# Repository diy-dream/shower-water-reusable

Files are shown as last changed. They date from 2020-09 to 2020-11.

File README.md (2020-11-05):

# Shower water reusable

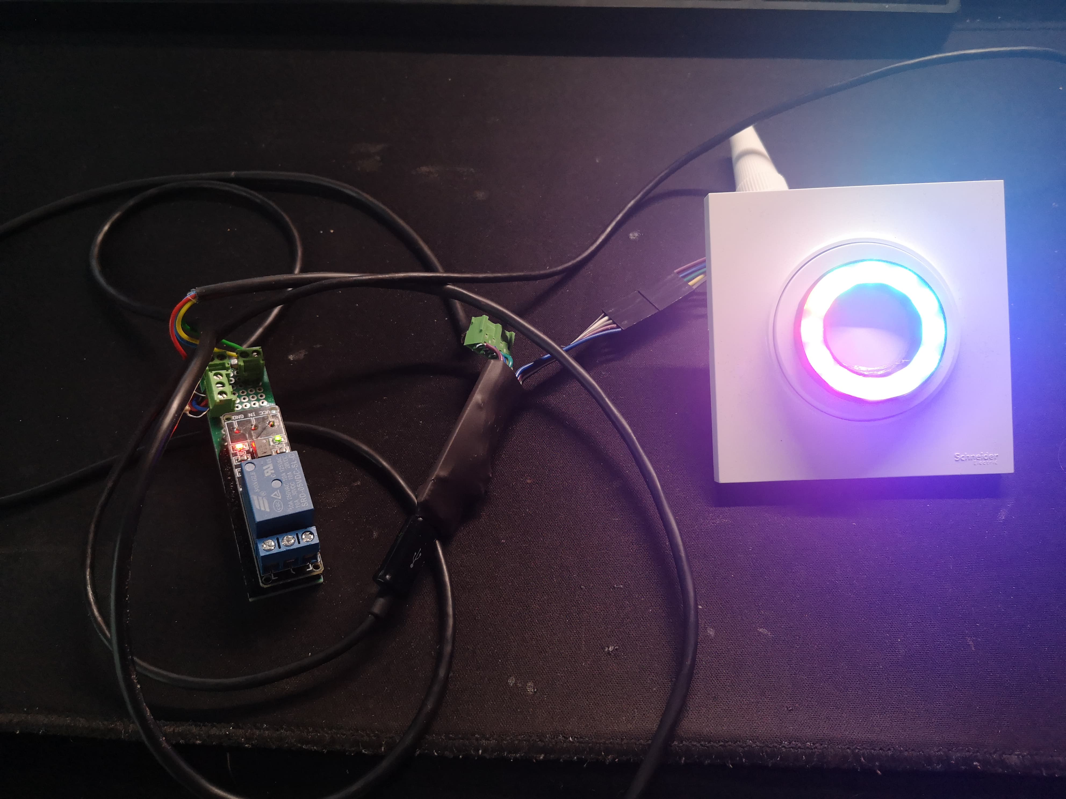
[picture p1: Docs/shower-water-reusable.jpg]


## Table of contents
* [Summary](#summary)
* [Requirements](#requirements)
* [Hardware](#hardware)
* [LICENCE](#licence)

## Summary

The idea of this project is to set up a system for reused the the cold water from the shower. This project is intended for my parents who have tanks to collect rainwater which allows them to supply the toilets with water and also to water the plants in summer.

When we take a shower we wait for the water to get hot, so we are wasting water that could very well be used for something else. So I created a system that allows cold water to be sent to the tubs and to detect / notify when the shower water is ready for the user.

## Requirements

* STM32CubeIDE 1.4.0

## Hardware

* STM32L412kb
* LED Ring 5V RGB WS2812B 12-Bit 37mm
* DS18B20
* Module relay 5V

## LICENCE	

TODO

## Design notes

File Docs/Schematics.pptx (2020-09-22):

## DAD PROJECT

Shower water reusable

## Schematics

Power Supply

5V

RGB RING

5V

D2

Temperature sensor

5V

VCC

D6

GND

GND

5V

GND

Arduino

D1

10 kOhms

GND

Switch

Solenoid valve

Relay

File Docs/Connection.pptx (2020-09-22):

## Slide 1

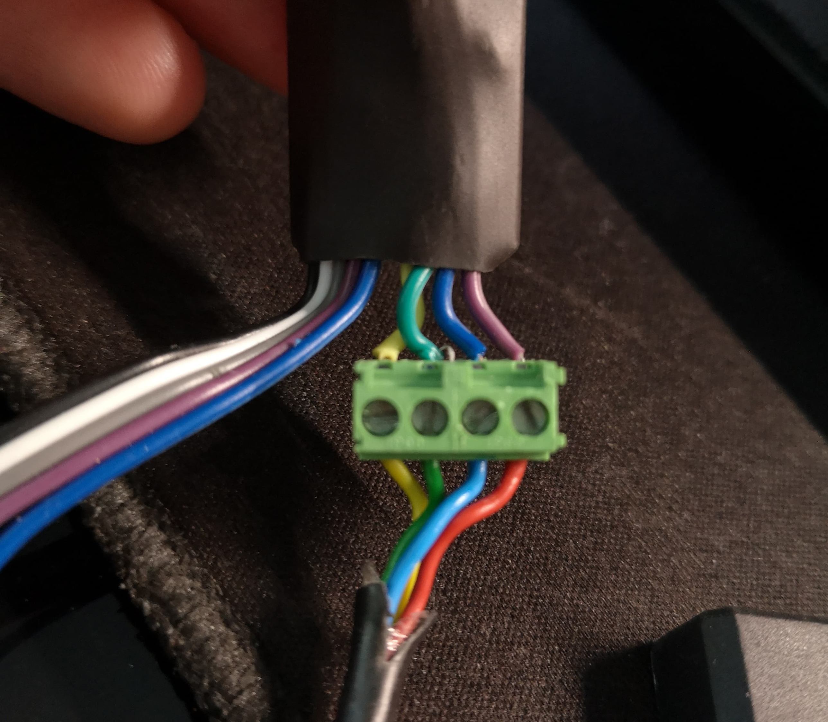
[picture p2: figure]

RELAY | TEMP | VCC | GND

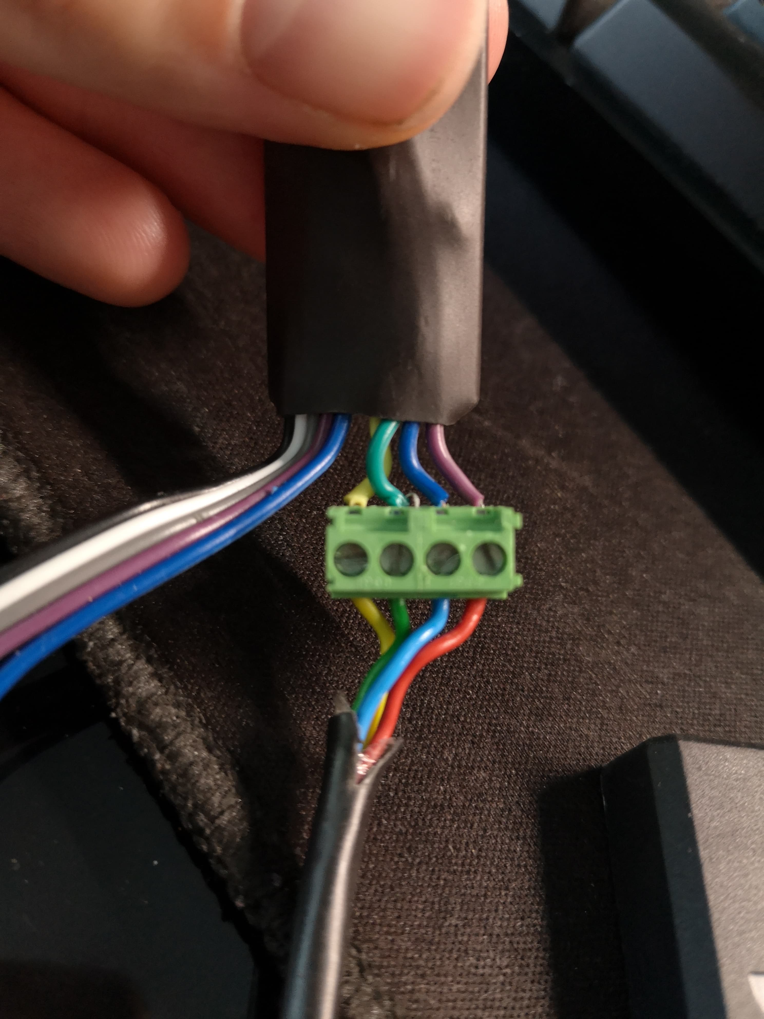
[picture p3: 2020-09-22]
Docs/connection.jpg

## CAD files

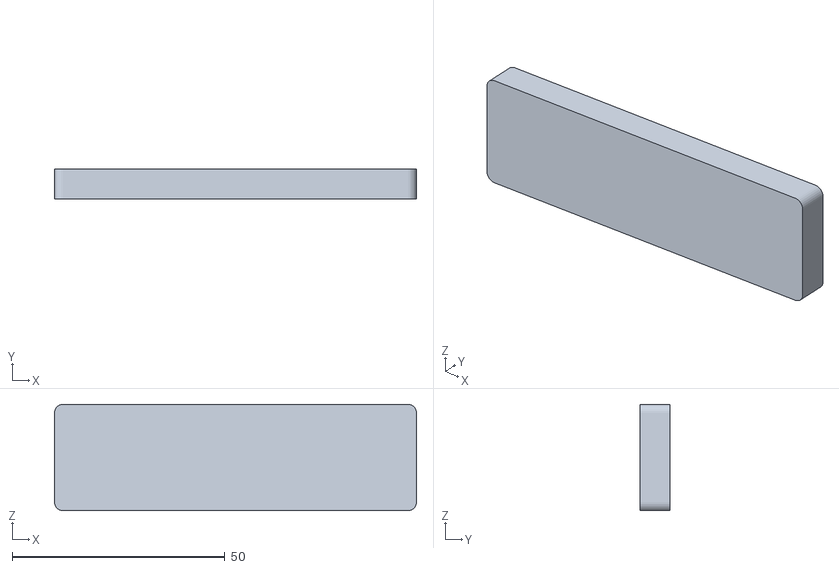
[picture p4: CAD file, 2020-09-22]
3d-model/RELAY_CASE_PART_1 v2.stl
85.0 x 7.00 x 25.0

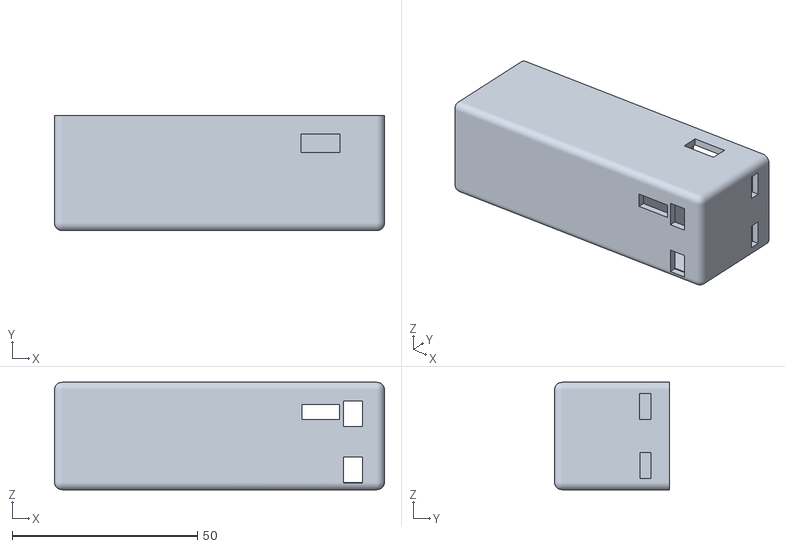
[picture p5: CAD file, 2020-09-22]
3d-model/RELAY_CASE_PART_2 v2.stl
89.0 x 31.0 x 29.0

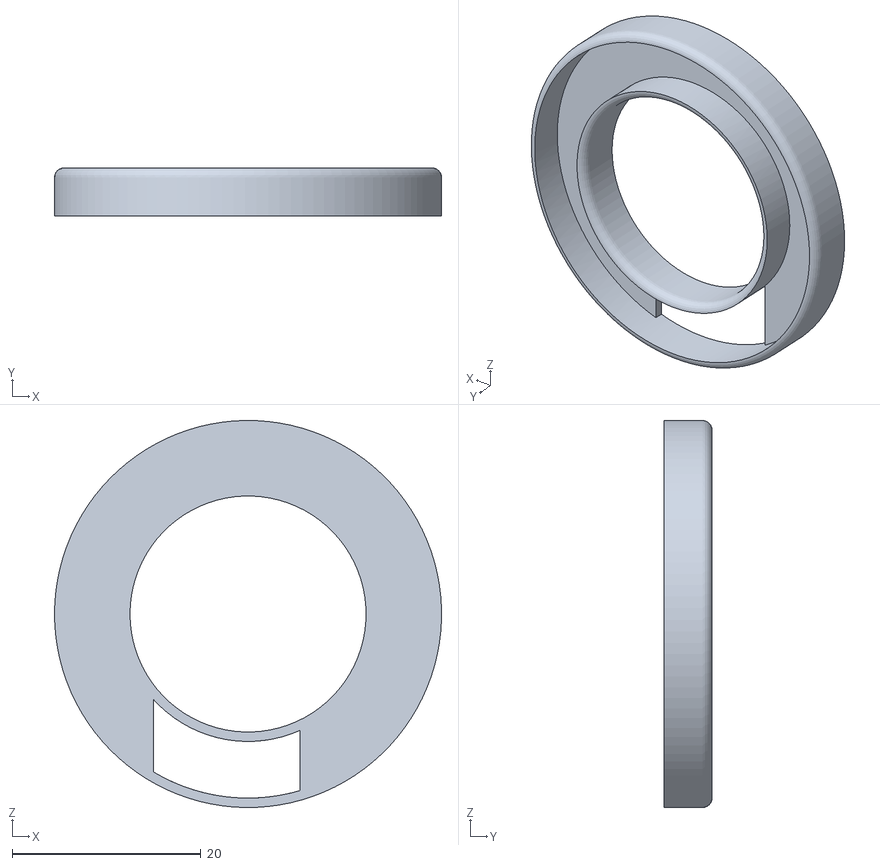
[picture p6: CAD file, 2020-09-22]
3d-model/RING_RGB_LED_SUPPORT v4.stl
41.0 x 5.10 x 41.0

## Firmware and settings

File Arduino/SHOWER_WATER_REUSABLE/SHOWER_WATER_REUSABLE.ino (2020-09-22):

#include "LowPower.h"
#include <OneWire.h>
#include <DallasTemperature.h>
#include <Adafruit_NeoPixel.h>
#include <SimpleCLI.h>

#define DEFAULT_TEMP_MIN 20 
#define DEFAULT_TEMP_MAX 28

#define TIMEOUT_FINISH 10
#define TIMEOUT_ERROR 10

#define RING_LEDS_PIN 6

// Data wire is plugged into port 3 on the Arduino
#define ONE_WIRE_BUS 3

#define SOLENOID_VALVE_PIN 4

#define SWITCH_PIN 2

// Parameter 1 = number of pixels in strip
// Parameter 2 = Arduino pin number (most are valid)
// Parameter 3 = pixel type flags, add together as needed:
//   NEO_KHZ800  800 KHz bitstream (most NeoPixel products w/WS2812 LEDs)
//   NEO_KHZ400  400 KHz (classic 'v1' (not v2) FLORA pixels, WS2811 drivers)
//   NEO_GRB     Pixels are wired for GRB bitstream (most NeoPixel products)
//   NEO_RGB     Pixels are wired for RGB bitstream (v1 FLORA pixels, not v2)
//   NEO_RGBW    Pixels are wired for RGBW bitstream (NeoPixel RGBW products)
Adafruit_NeoPixel strip = Adafruit_NeoPixel(12, RING_LEDS_PIN, NEO_GRB + NEO_KHZ800);

// Setup a oneWire instance to communicate with any OneWire devices (not just Maxim/Dallas temperature ICs)
OneWire oneWire(ONE_WIRE_BUS);

// Pass our oneWire reference to Dallas Temperature. 
DallasTemperature sensors(&oneWire);

// Create CLI Object
SimpleCLI cli;

// Commands
Command cmdSetMaxTemp;
Command cmdSetMinTemp;
Command cmdGetTemp;
Command cmdHelp;

bool flash = false;
uint8_t timeout_finish = 0;
uint8_t timeout_error = 0;

uint8_t tempMax = DEFAULT_TEMP_MAX;

float getTemperature(){
  // request to all devices on the bus
  Serial.print("Requesting temperatures...");
  sensors.requestTemperatures(); // Send the command to get temperatures
  Serial.println("DONE");
  
  return sensors.getTempCByIndex(0);
}

void wakeUp()
{ 
    bool isFinish = false;
    timeout_finish = 0;
    timeout_error = 0;
    uint8_t counter = 0;
    
    // Just a handler for the pin interrupt.
    
    // Disable external pin interrupt on wake up pin.
    detachInterrupt(0);

    //while(!isFinish || timeout_error < TIMEOUT_ERROR){
    while(timeout_error < TIMEOUT_ERROR){

      float temp = getTemperature();
      
      Serial.print("Temperature : ");
      Serial.println(temp);

      if(temp == -127 && counter < 3){
        counter++;
      } else if(temp == -127 && counter == 3){
        //Error temperature sensor

        //Turn off the solenoid valve
        digitalWrite(SOLENOID_VALVE_PIN, LOW);
        Serial.println("Error temperature sensor");
        
        timeout_finish = 0;
        while(timeout_finish < TIMEOUT_FINISH){
            if(flash){
              flash = false;
              colorWipe(strip.Color(240, 195, 0), 0); // Orange
            }else{
              flash = true;
              colorWipe(0, 0); // Turn off the ring leds off
            }
            timeout_finish++;
            delay(400);
        }
        colorWipe(0, 0); // Turn off the ring leds off
        break;
      }
    
      if(temp > tempMax){
        //Turn off the solenoid valve
        Serial.println("The temperature is higher than TEMP_MAX");

        digitalWrite(SOLENOID_VALVE_PIN, LOW);
        colorWipe(strip.Color(0, 255, 0), 50); // Green
        while(timeout_finish < TIMEOUT_FINISH){
          if(flash){
            flash = false;
            colorWipe(strip.Color(0, 255, 0), 0); // Green
          }else{
            flash = true;
            colorWipe(0, 0); // Turn off the ring leds off
          }
          timeout_finish++;
          delay(400);
        }

        colorWipe(0, 0); // Turn off the ring leds off
        isFinish = true;
      }else{
        Serial.println("The temperature is lower than TEMP_MAX");
        
        //Turn on the solenoid valve
        digitalWrite(SOLENOID_VALVE_PIN, HIGH);
        
        colorWipe(strip.Color(255, 0, 0), 50); // Red
        colorWipe(0, 50); // Red
      }
      
      timeout_error++;
      Serial.print("timeout_error = ");
      Serial.println(timeout_error);
    }

    if(timeout_error == TIMEOUT_ERROR){
      //Turn off the solenoid valve
      digitalWrite(SOLENOID_VALVE_PIN, LOW);
      Serial.println("Timeout to get a good temperature");
      
      timeout_finish = 0;
      while(timeout_finish < TIMEOUT_FINISH){
          if(flash){
            flash = false;
            colorWipe(strip.Color(44, 117, 255), 0); // Orange
          }else{
            flash = true;
            colorWipe(0, 0); // Turn off the ring leds off
          }
          timeout_finish++;
          delay(400);
      }
      colorWipe(0, 0); // Turn off the ring leds off
    }
    
    // WAKE-UP configuration
    // Allow wake up pin to trigger interrupt on low.
    attachInterrupt(0, wakeUp, LOW);

    // Enter power down state with ADC and BOD module disabled.
    // Wake up when wake up pin is low.
    LowPower.powerDown(SLEEP_FOREVER, ADC_OFF, BOD_OFF); 
}

void setup() {
  Serial.begin(115200);

  //CLI init
  cmdSetMaxTemp = cli.addCmd("temp");
  cmdSetMaxTemp.addArg("max");
  cmdSetMaxTemp.setDescription("Set the max temperature");

  cmdSetMinTemp = cli.addCmd("temp");
  cmdSetMinTemp.addArg("min");
  cmdSetMinTemp.setDescription("Set the min temperature");

  cmdGetTemp = cli.addCmd("getTemp");
  cmdGetTemp.setDescription("Get the actual temperature");

  cmdHelp = cli.addCommand("help");
  cmdHelp.setDescription(" Get help!");
  
  strip.begin();
  strip.show(); // Initialize all pixels to 'off'

  // Start up the library
  sensors.begin();

  //Solenoid valve init
  pinMode(SOLENOID_VALVE_PIN, OUTPUT);

  //Switch init
  pinMode(SWITCH_PIN, INPUT);

  // WAKE-UP configuration
  // Allow wake up pin to trigger interrupt on low.
  attachInterrupt(0, wakeUp, LOW);

  // Enter power down state with ADC and BOD module disabled.
  // Wake up when wake up pin is low.
  LowPower.powerDown(SLEEP_FOREVER, ADC_OFF, BOD_OFF); 
}

void loop() {
    if (Serial.available()) {
        String input = Serial.readStringUntil('\n');

        if (input.length() > 0) {
            Serial.print("# ");
            Serial.println(input);

            cli.parse(input);
        }
    }

    if (cli.available()) {
        Command c = cli.getCmd();

        int argNum = c.countArgs();

        Serial.print("> ");
        Serial.print(c.getName());
        Serial.print(' ');

        for (int i = 0; i<argNum; ++i) {
            Argument arg = c.getArgument(i);
            // if(arg.isSet()) {
            Serial.print(arg.toString());
            Serial.print(' ');
            // }
        }

        Serial.println();

        if (c == cmdSetMaxTemp) {
            Serial.println("The new maximum temperature = " + c.getArgument("max").getValue());
            tempMax = c.getArgument("max").getValue().toInt();
        } else if (c == cmdSetMinTemp) {
            Serial.println("cmdGetTemp new minimum temperature = " + c.getArgument("min").getValue());
        } else if (c == cmdGetTemp) {
            Serial.print("The temperature = ");        
            Serial.println(getTemperature());        
        } else if (c == cmdHelp) {
            Serial.println("Help:");
            Serial.println(cli.toString());
        }
    }

    if (cli.errored()) {
        CommandError cmdError = cli.getError();

        Serial.print("ERROR: ");
        Serial.println(cmdError.toString());

        if (cmdError.hasCommand()) {
            Serial.print("Did you mean \"");
            Serial.print(cmdError.getCommand().toString());
            Serial.println("\"?");
        }
    }
}

// Fill the dots one after the other with a color
void colorWipe(uint32_t c, uint8_t wait) {
  for(uint16_t i=0; i<strip.numPixels(); i++) {
    strip.setPixelColor(i, c);
    //bstrip.setBrightnessPixelColor(i, c);
    strip.show();
    delay(wait);
  }
}

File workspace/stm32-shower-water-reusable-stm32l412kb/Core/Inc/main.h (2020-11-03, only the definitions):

#define VCP_TX_Pin GPIO_PIN_2
#define VCP_TX_GPIO_Port GPIOA
#define controlSwitch_Pin GPIO_PIN_3
#define controlSwitch_GPIO_Port GPIOA
#define controlSwitch_EXTI_IRQn EXTI3_IRQn
#define relayControl_Pin GPIO_PIN_7
#define relayControl_GPIO_Port GPIOA
#define SWDIO_Pin GPIO_PIN_13
#define SWDIO_GPIO_Port GPIOA
#define SWCLK_Pin GPIO_PIN_14
#define SWCLK_GPIO_Port GPIOA
#define VCP_RX_Pin GPIO_PIN_15
#define VCP_RX_GPIO_Port GPIOA
#define LD3_Pin GPIO_PIN_3
#define LD3_GPIO_Port GPIOB
#define WS2812_FREQ											(800000) 			// it is fixed: WS2812 require 800kHz
#define TIMER_CLOCK_FREQ									(16000000)   	// can be modified - multiples of 0.8MHz are suggested
#define TIMER_PERIOD										(TIMER_CLOCK_FREQ / WS2812_FREQ)
#define LED_NUMBER											(16)					// how many LEDs the MCU should control?
#define LED_DATA_SIZE										(LED_NUMBER * 24)
#define RESET_SLOTS_BEGIN									(50)
#define RESET_SLOTS_END										(50)
#define WS2812_LAST_SLOT									(1)
#define LED_BUFFER_SIZE										(RESET_SLOTS_BEGIN + LED_DATA_SIZE + WS2812_LAST_SLOT + RESET_SLOTS_END)
#define WS2812_0											(TIMER_PERIOD / 3)				// WS2812's zero high time is long about one third of the period
#define WS2812_1											(TIMER_PERIOD * 2 / 3)		// WS2812's one high time is long about two thirds of the period
#define WS2812_RESET										(0)
#define TEST_TIME											(1)
#define BUTTON_TIMER_CLOCK_FREQ								(8000000)
#define BUTTON_TIMER_PERIOD 								(BUTTON_TIMER_CLOCK_FREQ * TEST_TIME)
#define CORRECT_TEMPERATURE									(20)
#define MAX_ERROR_COUNT										(2)
#define TEMPERATURE_ERROR_TIME								(60000) /* The value is expressed in milliseconds */

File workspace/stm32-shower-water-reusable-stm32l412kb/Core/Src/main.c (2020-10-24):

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
/* Includes ------------------------------------------------------------------*/
#include "main.h"
#include "cmsis_os.h"
#include "dma.h"
#include "tim.h"
#include "usart.h"
#include "gpio.h"

/* USER CODE BEGIN Includes */
#include <stdio.h>
#include <stdbool.h>
#include <stdarg.h>
#include "WS2812.h"
#include "stripEffects.h"
#include "lwow/lwow.h"
#include "lwow/devices/lwow_device_ds18x20.h"
#include "scan_devices.h"
#include "Buttons.h"
/* USER CODE END Includes */


void SystemClock_Config(void);
void MX_FREERTOS_Init(void);
/* USER CODE BEGIN 0 */
void safeprintf(const char* fmt, ...) {
    va_list va;

    va_start(va, fmt);
    osKernelLock();
    vprintf(fmt, va);
    osKernelUnlock();
    va_end(va);
}
/* USER CODE END 0 */

/**
  * @brief  The application entry point.
  * @retval int
  */
int main(void)
{
  /* MCU Configuration--------------------------------------------------------*/

  /* Reset of all peripherals, Initializes the Flash interface and the Systick. */
  HAL_Init();

  /* Configure the system clock */
  SystemClock_Config();

  /* Initialize all configured peripherals */
  MX_GPIO_Init();
  MX_USART2_UART_Init();
  MX_DMA_Init();
  MX_TIM1_Init();
  MX_USART1_UART_Init();
  /* USER CODE BEGIN 2 */
  printf("Application running on STM32L412KB-Nucleo board!\r\n");
  /* USER CODE END 2 */

  /* Init scheduler */
  osKernelInitialize();  /* Call init function for freertos objects (in freertos.c) */
  MX_FREERTOS_Init();
  /* Start scheduler */
  osKernelStart();

  /* We should never get here as control is now taken by the scheduler */
  /* Infinite loop */
  /* USER CODE BEGIN WHILE */
  while (1)
  {
    /* USER CODE END WHILE */

    /* USER CODE BEGIN 3 */
  }
  /* USER CODE END 3 */
}

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
/* USER CODE BEGIN 4 */
/**
 * \brief           Printf character handler
 * \param[in]       ch: Character to send
 * \param[in]       f: File pointer
 * \return          Written character
 */
#ifdef __GNUC__
int __io_putchar(int ch) {
#else
int fputc(int ch, FILE* fil) {
#endif
    uint8_t c = (uint8_t)ch;
    HAL_UART_Transmit(&huart2, &c, 1, 100);
    return ch;
}
/* USER CODE END 4 */

/**
  * @brief  Period elapsed callback in non blocking mode
  * @note   This function is called  when TIM6 interrupt took place, inside
  * HAL_TIM_IRQHandler(). It makes a direct call to HAL_IncTick() to increment
  * a global variable "uwTick" used as application time base.
  * @param  htim : TIM handle
  * @retval None
  */
void HAL_TIM_PeriodElapsedCallback(TIM_HandleTypeDef *htim)
{
  if (htim->Instance == TIM6) {
    HAL_IncTick();
  }
  /* USER CODE BEGIN Callback 1 */
  else if(htim->Instance == TIM2) {
	  //Button_Timer_Callback();
  }
  /* USER CODE END Callback 1 */
}

/**
  * @brief  This function is executed in case of error occurrence.
  * @retval None
  */
void Error_Handler(void)
{
  /* USER CODE BEGIN Error_Handler_Debug */
  /* User can add his own implementation to report the HAL error return state */

  /* USER CODE END Error_Handler_Debug */
}

#ifdef  USE_FULL_ASSERT
/**
  * @brief  Reports the name of the source file and the source line number
  *         where the assert_param error has occurred.
  * @param  file: pointer to the source file name
  * @param  line: assert_param error line source number
  * @retval None
  */
void assert_failed(uint8_t *file, uint32_t line)
{
}
#endif /* USE_FULL_ASSERT */

/************************ (C) COPYRIGHT STMicroelectronics *****END OF FILE****/

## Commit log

2020-09-22 First commit with : - First version of the software - Documentation : - Datasheet - Connection - 3D model files of the RGB ring support and relay protection
    [RELAY_CASE_PART_1 v2.stl, RELAY_CASE_PART_2 v2.stl, RING_RGB_LED_SUPPORT v4.stl]
2020-10-24 Fix temperature control to open the water valve
    [main.c]
2020-10-24 Fix counter variable of temperature control
    [main.c]
2020-10-24 Fixed button state acquisition to improve the "aborted" option
    [main.c]
2020-10-24 Fixed the last commit about the activation of the water valve
    [main.c]
2020-10-25 Photo of the first prototype
2020-10-25 Add protection if the boiler does not heat (broken / off)
    [main.h]
2020-11-03 Close the valve on timeout (60s)

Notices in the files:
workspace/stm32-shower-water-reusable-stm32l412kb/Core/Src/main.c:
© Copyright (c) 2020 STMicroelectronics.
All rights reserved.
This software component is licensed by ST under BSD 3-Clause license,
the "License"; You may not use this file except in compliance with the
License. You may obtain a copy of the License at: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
